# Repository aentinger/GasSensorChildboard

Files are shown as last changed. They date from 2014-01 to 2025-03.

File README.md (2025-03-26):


💾 Gas Sensor Childboard
========================



# 📸 Image

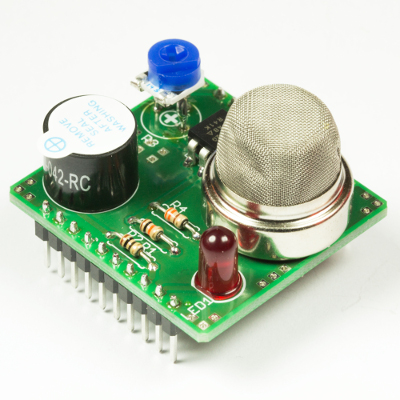
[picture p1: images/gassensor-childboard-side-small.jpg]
LXRobotics P6_1 Gassensor Childboard


# 📂 Description

The LXRobotics Gas Sensor Childboard can be used to sense various gas types e.g. LPG, butane, propane, methane, alcohol, hydrogen, smoke. The sensitivity of the sensor can be adjusted via potentiometer. A user controllable red LED and a piezo buzzer are used for signalling alarm/warning states. For a quick and easy start, an open source Arduino library with sample programs is available.

**Features**

* MQ-2 gas sensor (LPG, butane, propane, methane, alcohol, hydrogen, smoke)
* Power supply of the gas sensor can be turned off in order to save energy
* Adjustable sensitivity of the gas sensor via potentiometer
* Piezo-buzzer for alarm tones
* Red signal LED
* Can be used with the Radioshield and the Childboard Adaptershield
* Arduino Library with example programs is available on GitHub

# 🎥 [Video](images/gas_sensor_childboard_demo.mp4)

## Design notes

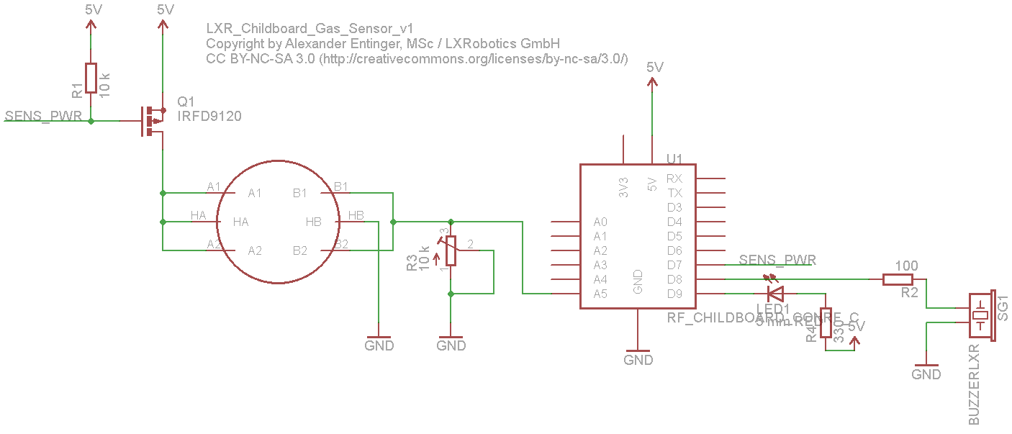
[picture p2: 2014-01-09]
hardware/lxr_childboard_gas_sensor_v1.png

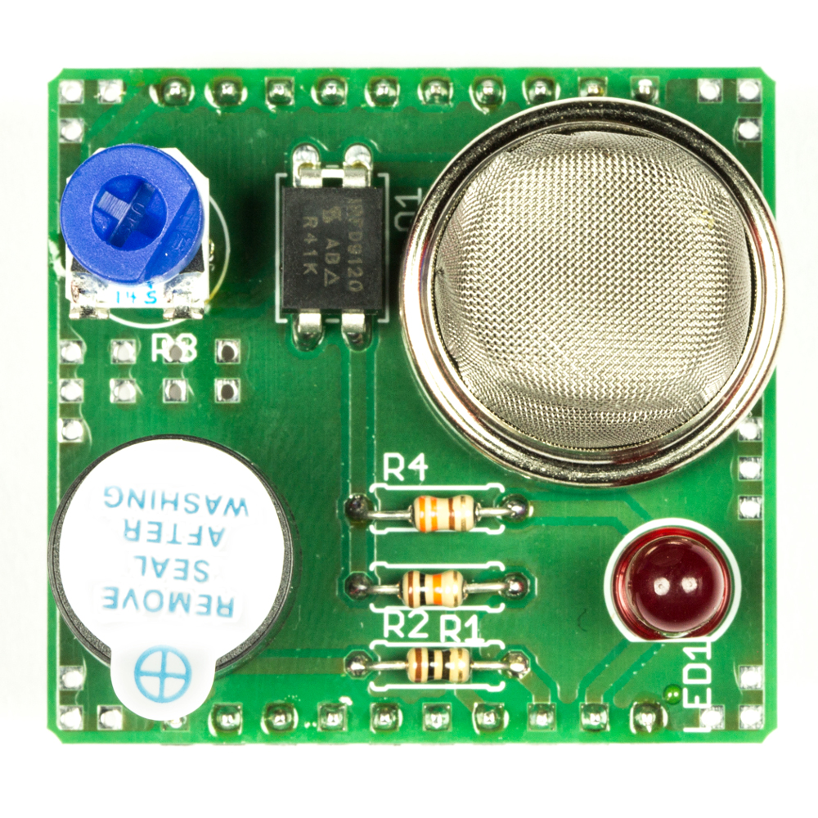
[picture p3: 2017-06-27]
images/gassensor-childboard-top-large.jpg

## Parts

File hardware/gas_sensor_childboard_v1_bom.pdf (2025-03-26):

Menge | Schaltplan | Bezeichnung | Farnell/Conrad Bestell Nummer | Preis (1 Stück) | Gesamtpreis | Wird bestückt | Footprint | Säckchen | ESD
2 | U1 | RF Childboard Connector | 1022261 | € 0,36 | € 0,72 | | | S1
1 | IC1 | P-Kanal-MOSFET, DIL, IRFD9120 | 9103244 | € 1,21 | € 1,21 | | | S3
1 | R1 | Widerstand, bedrahtet, 10 k, 1/4 W | 2329474 | € 0,03 | € 0,03 | | | S2 | x
1 | SG1 | Piezo Summer | 1827949 | € 2,34 | € 2,34 | | | S1
1 | R2 | Widerstand, bedrahtet, 10 Ohm, 1/8 W | 1700210 | € 0,01 | € 0,01 | | | S2 | x
1 | R3 | 10 k Drehpotentiometer, 0.3 W | 108239 | € 0,38 | € 0,38
1 | LED1 | LED Rot, 5 mm, 10 mA, 1.9 V | 1003211 | € 0,19 | € 0,19 | | | S3
1 | R4 | Widerstand, bedrahtet, 330 Ohm, 1/4 W | 2329514 | € 0,03 | € 0,03 | | | S2 | x
1 | MQ-2 Gas-Sensor | € | 4,00 | € | 4,00 | - | http://www.pololu.com/product/1480
1 | Leitfähiger Schaumstoff | 1687855 | € | 2,40 | € | 2,40 | - | Bestellung von 1 Stück für 50 Gassensor Childboards ausreichend
| | | Summe | | € | 8,92

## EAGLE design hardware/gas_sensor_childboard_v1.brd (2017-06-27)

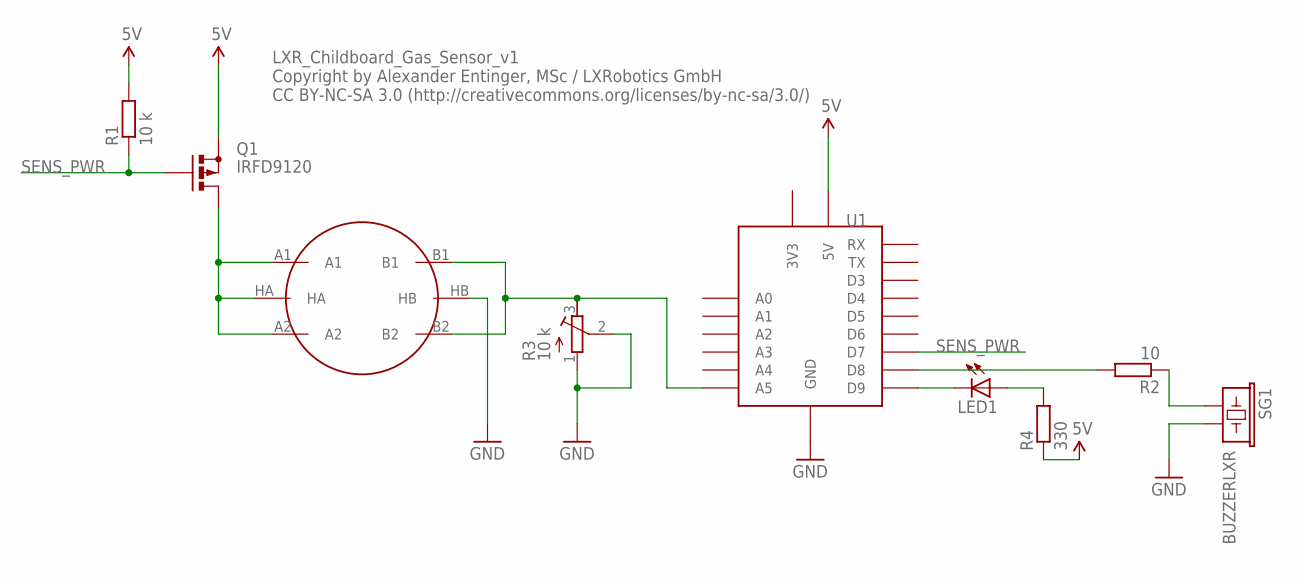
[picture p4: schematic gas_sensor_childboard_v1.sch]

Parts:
LED1: 5 mm RED; LED5MM
MQ-2: METHANE_SENSOR; MQ-3
Q1: IRFD9120; C370-01
R1: 10 k; 0207/7
R2: 10; 0207/7
R3: 10 k; RTRIM3339P
R4: 330; 0207/7
SG1: BUZZERLXR; BUZZER_LXR
U1: RF_CHILDBOARD_CONRF_C; RF_CHILDBOARD_CON

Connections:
5V: Q1.S, R1.2, R4.1, U1.5V
GND: MQ-2.HB, R3.1 (E), R3.2 (S), SG1.2, U1.GND, U1.GND1 (GND), U1.GND2 (GND)
unnamed: MQ-2.A1, MQ-2.A2, MQ-2.HA, Q1.D, Q1.D1 (D)
unnamed: MQ-2.B1, MQ-2.B2, R3.3 (A), U1.A5
unnamed: R2.1, SG1.1
unnamed: R2.2, U1.D8
unnamed: LED1.A, R4.2
unnamed: LED1.K (C), U1.D9
SENS_PWR: Q1.G, R1.1, U1.D7

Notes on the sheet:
LXR_Childboard_Gas_Sensor_v1 Copyright by Alexander Entinger, MSc / LXRobotics GmbH CC BY-NC-SA 3.0 (http://creativecommons.org/licenses/by-nc-sa/3.0/)

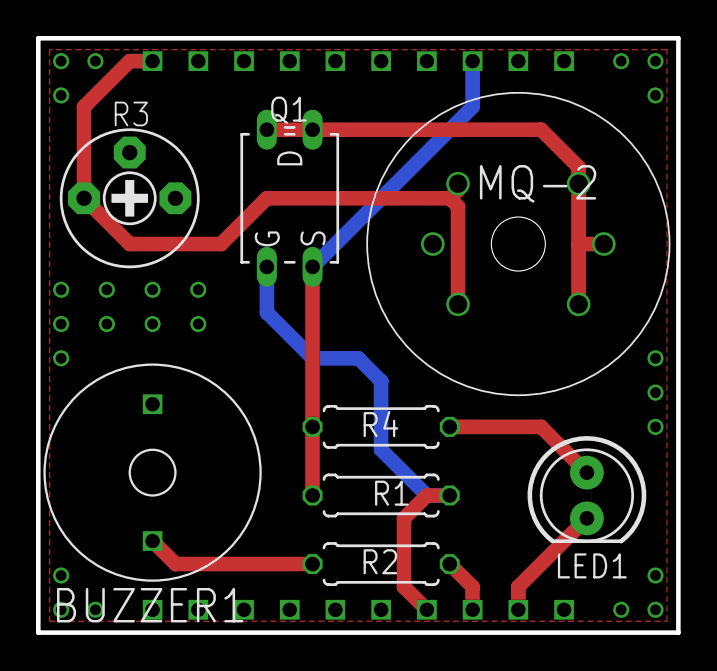
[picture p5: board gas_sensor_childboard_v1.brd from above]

Board: 2 copper layers, 35.6 x 33.0 mm, 9 parts (0 on the bottom side), 9 nets.

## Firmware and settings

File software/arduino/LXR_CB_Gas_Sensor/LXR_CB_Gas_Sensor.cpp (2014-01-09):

/**
 * @author Alexander Entinger, MSc / LXRobotics
 * @brief this module implements the library for controlling the LXRobotics Gassensor Childboard
 * @file LXR_CB_Gas_Sensor.cpp
 * @license Attribution-NonCommercial-ShareAlike 3.0 Unported (CC BY-NC-SA 3.0) ( http://creativecommons.org/licenses/by-nc-sa/3.0/ )
 */

#include "LXR_CB_Gas_Sensor.h"

#define BUZZER_PERIOD_US           (434)
#define BUZZER_PERIOD_HALF_US      (BUZZER_PERIOD_US/2)
#define TIMER2_TIMERSTEP_US        (2)
#define TIMER2_RELOAD_VALUE        (255 - BUZZER_PERIOD_HALF_US/TIMER2_TIMERSTEP_US)

static int const red_led_pin = 9; // D9
static int const alarm_buzzer_pin = 8; // D8
static volatile boolean m_buzzer_activated = false;
static int const sensor_power_pin = 7; // D7
static int const sensor_adc_pin = 5; // A5

/**
 * @brief this function initializes the childboard
 */
void LXR_CB_Gas_Sensor::begin() {
  // set led pin to output and high (led deactivated)
  pinMode(red_led_pin, OUTPUT);
  digitalWrite(red_led_pin, HIGH);
  // set buzzer pin to output and low (buzzer deactivated)
  pinMode(alarm_buzzer_pin, OUTPUT);
  digitalWrite(alarm_buzzer_pin, LOW);
  // init timer 2 for buzzer
  TCNT2 = TIMER2_RELOAD_VALUE;  // preload timer 2 with reload value
  TIMSK2 = (1<<TOIE2); // enable timer 2 overflow interrupt
  TCCR2B = (1<<CS21) | (1<<CS20); // activate timer 2, timer 2 prescaler = 32, 1 Timerstep = 2 us
  // set sensor power pin to output and high (power supply for sensor deactivated)
  pinMode(sensor_power_pin, OUTPUT);
  digitalWrite(sensor_power_pin, HIGH);
}

/**
 * @brief functions for turning on and off the red led
 */
void LXR_CB_Gas_Sensor::turn_on_led() {
  digitalWrite(red_led_pin, LOW);
}
void LXR_CB_Gas_Sensor::turn_off_led() {
  digitalWrite(red_led_pin, HIGH);
}

/**
 * @brief functions for turning on and off the alarm buzzer
 */
void LXR_CB_Gas_Sensor::turn_on_alarm() {
  m_buzzer_activated = true;
}
void LXR_CB_Gas_Sensor::turn_off_alarm() {
  m_buzzer_activated = false;
}

/**
 * @brief interrupt service routine for the buzzer
 */
static boolean is_buzzer_on = false;
ISR(TIMER2_OVF_vect) {
  TCNT2 = TIMER2_RELOAD_VALUE;
  if(m_buzzer_activated) {
    if(is_buzzer_on) digitalWrite(alarm_buzzer_pin, HIGH);
    else digitalWrite(alarm_buzzer_pin, LOW);
    is_buzzer_on = !is_buzzer_on;
  } else {
   digitalWrite(alarm_buzzer_pin, LOW);
  }
}

/**
 * @brief functions for turning on and off the power supply for the gas sensor
 */
void LXR_CB_Gas_Sensor::turn_on_sensor() {
  digitalWrite(sensor_power_pin, LOW);
}
void LXR_CB_Gas_Sensor::turn_off_sensor() {
 digitalWrite(sensor_power_pin, HIGH);
}

/**
 * @brief returns the voltages measured after the voltage divider - this value is proportional to the amount of gas in the air for finetuning use the potentiometer
 */
int LXR_CB_Gas_Sensor::read_gas_sensor() {
  return analogRead(sensor_adc_pin);
}

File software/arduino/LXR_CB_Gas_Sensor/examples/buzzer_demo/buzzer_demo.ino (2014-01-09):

/** 
 * @author Alexander Entinger MSc, LXRobotics
 * @brief this file demonstrates how to use the LXR_CB_Gas_Sensor library to turn on and off the alarm buzzer of the gas sensor childboard
 * @file buzzer_demo.ino
 * @license Attribution-NonCommercial-ShareAlike 3.0 Unported (CC BY-NC-SA 3.0) ( http://creativecommons.org/licenses/by-nc-sa/3.0/ )
 */

#include "LXR_CB_Gas_Sensor.h"

void setup() {               
  // initialize the gas sensor childboard 
  LXR_CB_Gas_Sensor::begin();
}

void loop() {
  // turn buzzer on
  LXR_CB_Gas_Sensor::turn_on_alarm();
  delay(1000);
  // turn buzzer off
  LXR_CB_Gas_Sensor::turn_off_alarm();
  delay(1000);
}

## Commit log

2014-01-09 initial checkin of files for lxr childboard gas sensor
2017-06-27 Adding hardware + images
    [gas_sensor_childboard_v1.brd, gas_sensor_childboard_v1.sch]
2025-03-26 Upload BOM.

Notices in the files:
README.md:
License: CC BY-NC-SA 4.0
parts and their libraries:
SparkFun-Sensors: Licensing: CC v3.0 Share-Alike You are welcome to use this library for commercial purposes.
